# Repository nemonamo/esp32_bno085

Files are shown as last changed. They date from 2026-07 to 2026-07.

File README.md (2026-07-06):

<h1 align="center">ESP32 BNO085</h1>

<p align="center">
  <strong>9축 모션 센싱을 위한 ESP32-S3 + BNO085 KiCad 하드웨어 설계.</strong>
</p>

<p align="center">
  
  
  
  
</p>

<p align="center">
  <a href="#주요-특징">주요 특징</a> |
  <a href="#저장소-구성">구성</a> |
  <a href="#프로젝트-열기">열기</a> |
  <a href="#제작-체크리스트">제작</a> |
  <a href="#라이선스">라이선스</a>
</p>

<p align="center">
  한국어 |
  <a href="docs/i18n/README.en.md">English</a> |
  <a href="docs/i18n/README.zh-CN.md">中文</a> |
  <a href="docs/i18n/README.ja.md">日本語</a>
</p>

이 저장소는 BNO085 9축 스마트 IMU를 중심으로 한 소형 ESP32-S3 보드의 KiCad 설계 파일을 담고 있습니다. 회로도, PCB 레이아웃, 로컬 풋프린트 라이브러리, fabrication-toolkit 설정은 버전 관리하고, 생성된 Gerber와 분석 결과는 Git에 포함하지 않습니다.

## 주요 특징

- **ESP32-S3 모듈** - Wi-Fi/BLE가 가능한 MCU 모듈 풋프린트.
- **BNO085 스마트 IMU** - 가속도계, 자이로, 자력계, 센서 퓨전용 9축 센서.
- **USB-C 인터페이스** - USB 2.0 Type-C 리셉터클 기반 연결.
- **로컬 풋프린트 포함** - BNO085와 Molex 커넥터 풋프린트를 저장소에 포함.
- **제작 설정 버전 관리** - 반복 가능한 제조 파일 생성을 위한 fabrication-toolkit 설정 포함.

## 저장소 구성

```text
esp32_bno085.kicad_pro          KiCad 프로젝트 파일
esp32_bno085.kicad_sch          회로도
esp32_bno085.kicad_pcb          PCB 레이아웃
fp-lib-table                    로컬 풋프린트 라이브러리 테이블
BNO085.pretty/                  BNO085 풋프린트
530480210.pretty/               Molex 커넥터 풋프린트
fabrication-toolkit-options.json
```

생성 파일은 제외합니다.

```text
analysis/
production/
*-backups/
.history/
*.kicad_prl
```

## 프로젝트 열기

1. KiCad 8 이상을 설치합니다.
2. 저장소를 clone합니다.
3. KiCad에서 `esp32_bno085.kicad_pro`를 엽니다.
4. `fp-lib-table` 기준으로 로컬 풋프린트가 정상 연결되는지 확인합니다.
5. 제조 파일을 내보내기 전에 ERC와 DRC를 실행합니다.

```powershell
git clone https://github.com/nemonamo/esp32_bno085.git
cd esp32_bno085
```

## 제작 체크리스트

PCB 주문 전 확인할 항목:

- `esp32_bno085.kicad_sch`에서 KiCad ERC 실행
- `esp32_bno085.kicad_pcb`에서 KiCad DRC 실행
- 현재 보드 기준으로 Gerber, drill, BOM, CPL 재내보내기
- USB D+/D- clearance와 커넥터 방향 확인
- BNO085 I2C pull-up과 전원 레일 확인
- 제작 업체의 설계 규칙이 현재 PCB 제약과 맞는지 확인

이전 보드 리뷰에서는 JLCPCB 관련 copper geometry, 작은 via, USB D- clearance, silkscreen/text warning, BNO085 environmental I2C pull-up을 중점적으로 확인했습니다. 레이아웃을 바꿀 때마다 검사를 다시 실행하세요.

## 이 저장소가 아닌 것

- 펌웨어는 포함하지 않습니다.
- 생성된 production package는 포함하지 않습니다.
- 최신 커밋이 그대로 제작 검증을 마쳤다고 보장하지 않습니다.

## 보안과 안전

하드웨어 저장소도 제작 압축 파일, 공급업체 export, 주문 파일, 스크린샷, 로컬 메모를 통해 개인 정보나 프로젝트 정보를 노출할 수 있습니다. production export와 분석 보고서는 검토 전까지 로컬에만 보관하세요.

## 라이선스

현재 오픈소스 하드웨어/소프트웨어 라이선스가 선언되어 있지 않습니다. 외부 재사용, 제작, 기여를 받기 전에 `LICENSE` 파일을 추가하세요.

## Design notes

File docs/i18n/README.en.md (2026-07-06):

<h1 align="center">ESP32 BNO085</h1>

<p align="center">
  <strong>A compact ESP32-S3 + BNO085 KiCad hardware design for 9-axis motion sensing.</strong>
</p>

<p align="center">
  <a href="../../README.md">한국어</a> |
  English |
  <a href="README.zh-CN.md">中文</a> |
  <a href="README.ja.md">日本語</a>
</p>

This repository contains the KiCad design files for a small ESP32-S3 board built around the BNO085 9-axis smart IMU. Schematic, PCB layout, footprint libraries, and fabrication-toolkit settings are tracked; generated Gerbers and local analysis outputs are excluded.

## Features

- **ESP32-S3 module** - Wi-Fi/BLE capable MCU module footprint.
- **BNO085 smart IMU** - accelerometer, gyroscope, magnetometer, and sensor-fusion capable sensor.
- **USB-C interface** - USB 2.0 Type-C receptacle.
- **Local footprints included** - BNO085 and Molex connector footprint libraries.
- **Fabrication-toolkit settings** - export options for repeatable manufacturing output.

## Repository Contents

```text
esp32_bno085.kicad_pro
esp32_bno085.kicad_sch
esp32_bno085.kicad_pcb
fp-lib-table
BNO085.pretty/
530480210.pretty/
fabrication-toolkit-options.json
```

## Open the Project

```powershell
git clone https://github.com/nemonamo/esp32_bno085.git
cd esp32_bno085
```

Open `esp32_bno085.kicad_pro` in KiCad 8 or newer, confirm local footprints resolve, then run ERC and DRC before exporting fabrication files.

## Fabrication Checklist

- Run KiCad ERC and DRC.
- Re-export Gerbers, drill files, BOM, and CPL.
- Review USB D+/D- clearance and connector orientation.
- Review BNO085 I2C pull-ups and power rails.
- Confirm fabrication-house design rules.

## Security and Safety

Keep generated archives, order files, supplier exports, screenshots, and local notes out of Git unless they have been reviewed.

## License

No open-source hardware or software license is currently declared. Add a `LICENSE` file before publishing this design for reuse, fabrication by others, or external contribution.

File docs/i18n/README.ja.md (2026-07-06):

<h1 align="center">ESP32 BNO085</h1>

<p align="center">
  <strong>9 軸モーションセンシング向け ESP32-S3 + BNO085 KiCad ハードウェア設計。</strong>
</p>

<p align="center">
  <a href="../../README.md">한국어</a> |
  <a href="README.en.md">English</a> |
  <a href="README.zh-CN.md">中文</a> |
  日本語
</p>

このリポジトリは、BNO085 9 軸スマート IMU を中心にした小型 ESP32-S3 ボードの KiCad 設計ファイルを含みます。回路図、PCB、ローカルフットプリント、fabrication-toolkit 設定を管理し、生成済み Gerber や分析出力は含めません。

## 機能

- **ESP32-S3 モジュール** - Wi-Fi/BLE 対応 MCU モジュールのフットプリント。
- **BNO085 スマート IMU** - 加速度、ジャイロ、磁気、センサーフュージョン。
- **USB-C インターフェース** - USB 2.0 Type-C レセプタクル。
- **ローカルフットプリント同梱** - BNO085 と Molex コネクタ用ライブラリ。
- **製造出力設定** - 再現性のある製造ファイル出力用設定。

## 内容

```text
esp32_bno085.kicad_pro
esp32_bno085.kicad_sch
esp32_bno085.kicad_pcb
fp-lib-table
BNO085.pretty/
530480210.pretty/
fabrication-toolkit-options.json
```

## プロジェクトを開く

```powershell
git clone https://github.com/nemonamo/esp32_bno085.git
cd esp32_bno085
```

KiCad 8 以降で `esp32_bno085.kicad_pro` を開き、ローカルフットプリントが解決できることを確認してから、製造ファイル出力前に ERC と DRC を実行してください。

## 製造チェック

- KiCad ERC と DRC を実行する。
- Gerber、ドリル、BOM、CPL を再出力する。
- USB D+/D- のクリアランスとコネクタ向きを確認する。
- BNO085 I2C プルアップと電源レールを確認する。
- 製造業者の設計ルールを確認する。

## 安全性

生成アーカイブ、注文ファイル、サプライヤー出力、スクリーンショット、ローカルメモは、レビュー前に Git に含めないでください。

## ライセンス

現在、オープンソースハードウェアまたはソフトウェアライセンスは宣言されていません。再利用、製造、外部貢献を受ける前に `LICENSE` ファイルを追加してください。

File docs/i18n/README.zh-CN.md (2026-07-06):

<h1 align="center">ESP32 BNO085</h1>

<p align="center">
  <strong>用于 9 轴运动感知的 ESP32-S3 + BNO085 KiCad 硬件设计。</strong>
</p>

<p align="center">
  <a href="../../README.md">한국어</a> |
  <a href="README.en.md">English</a> |
  中文 |
  <a href="README.ja.md">日本語</a>
</p>

本仓库包含围绕 BNO085 9 轴智能 IMU 设计的小型 ESP32-S3 板卡 KiCad 文件。仓库跟踪原理图、PCB、局部封装库和 fabrication-toolkit 设置，不包含生成的 Gerber 和本地分析输出。

## 功能

- **ESP32-S3 模块** - 支持 Wi-Fi/BLE 的 MCU 模块封装。
- **BNO085 智能 IMU** - 加速度计、陀螺仪、磁力计和传感器融合。
- **USB-C 接口** - USB 2.0 Type-C 接口。
- **包含本地封装** - BNO085 和 Molex 连接器封装库。
- **制造导出设置** - 用于可重复生成制造文件。

## 仓库内容

```text
esp32_bno085.kicad_pro
esp32_bno085.kicad_sch
esp32_bno085.kicad_pcb
fp-lib-table
BNO085.pretty/
530480210.pretty/
fabrication-toolkit-options.json
```

## 打开项目

```powershell
git clone https://github.com/nemonamo/esp32_bno085.git
cd esp32_bno085
```

使用 KiCad 8 或更新版本打开 `esp32_bno085.kicad_pro`，确认本地封装可解析，并在导出制造文件前运行 ERC 和 DRC。

## 制造检查

- 运行 KiCad ERC 和 DRC。
- 重新导出 Gerber、钻孔文件、BOM 和 CPL。
- 检查 USB D+/D- 间距和连接器方向。
- 检查 BNO085 I2C 上拉和电源轨。
- 确认制造厂设计规则。

## 安全

生成的压缩包、订单文件、供应商导出、截图和本地笔记在审核前不要提交到 Git。

## 许可证

当前未声明开源硬件或软件许可证。公开复用、制作或接受外部贡献前，请添加 `LICENSE` 文件。

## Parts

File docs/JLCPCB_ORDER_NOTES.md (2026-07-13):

# JLCPCB Order Notes

Last checked: 2026-07-13

Detailed current-state review: [`VERIFICATION_REPORT.md`](VERIFICATION_REPORT.md)

This board keeps the existing outline. Do not enlarge the PCB only to satisfy
assembly handling requirements. If JLCPCB asks for handling area, use a panel,
mouse bites, V-cut, or edge rails around the board.

## Current KiCad Checks

- KiCad 10 ERC: 0 violations.
- KiCad 10 PCB DRC with schematic parity: 0 violations, 0 unconnected items,
  0 schematic parity issues.
- If every project-ignored PCB check is temporarily enabled, the remaining
  warnings are footprint-library comparison warnings (`lib_footprint_mismatch`).
  They indicate that the board-embedded footprint copies differ from the
  currently installed KiCad library versions. They are not clearance,
  unconnected-net, or schematic-parity failures.
- R10/R11 now include B.CrtYd courtyard outlines, so they no longer trigger
  `missing_courtyard` when that normally ignored check is enabled.
- Board outline from the PCB file is about 24.5 mm x 53.4 mm.
- Q1 power-path orientation has been corrected: Q1 gate is on `+5V`, source is
  on `VSYS`, and drain is on `BAT`. This blocks USB-powered `VSYS` from
  backfeeding the battery through the P-MOSFET body diode.

## JLCPCB Assembly Constraints

- The PCB has SMD components on both F.Cu and B.Cu.
- Economic PCBA is single-sided placement. Use Standard PCBA for double-sided
  assembly, or move the assembled parts to one side before using Economic PCBA.
- Standard PCBA currently has a 70 mm x 70 mm minimum single-PCB/panel handling
  size. Keep the board outline unchanged and use a panel/rails if required.
- PCB-only top-side fiducials `FID1`-`FID3` have been added and are excluded
  from BOM and position files. For double-sided Standard PCBA, still review
  JLCPCB's panel/rail/fiducial handling during upload.

## Geometry Notes

- Current project rules use 0.1016 mm minimum track width/clearance.
- JLCPCB's current 1 oz 1/2-layer capability lists 0.10 mm / 0.10 mm minimum
  track width/spacing, so the 0.1016 mm routes are inside that published limit.
- Current default vias are 0.5 mm diameter / 0.3 mm drill. JLCPCB lists
  0.25 mm diameter / 0.15 mm hole as the minimum via capability, with 0.2 mm
  hole preferred, so these vias are not the limiting geometry.
- The USB-C and battery connector footprints intentionally extend to the board
  edge. Some generic DFM analyzers report this as an edge-clearance error, but
  it is not a KiCad DRC violation.
- Gerber analyzer layer-extent warnings are expected here because copper,
  paste, mask, drill, and edge layers naturally occupy different areas of the
  board. KiCad's generated job file reports the complete 24.7 mm x 53.6 mm
  board and all expected Gerber/drill layers are present.

## Via-In-Pad Note

There is a via at/near the D2 pad area. The raw PCB marks that via as capped,
covered, plugged, and filled on both sides. For assembled boards, confirm that
the selected JLCPCB via process honors this, or choose epoxy-filled and capped
or copper-filled and capped vias where needed. JLCPCB notes that vias in pads
cannot be plugged with ink and should use epoxy or copper filling when that
finish is required.

## BOM/CPL Handoff

- Local, ignored-by-git JLCPCB outputs were regenerated under
  `production/jlcpcb_20260713_q1_fix/`: `gerbers.zip`,
  `jlcpcb_bom.csv`, `jlcpcb_cpl_smd_only.csv`, and
  `jlcpcb_cpl_all_components.csv`.
- The normalized BOM has 23 rows. Seven rows have LCSC part numbers and 16 rows
  remain blank until exact lab/JLCPCB part choices are finalized.
- KiCad `MPN`, `Manufacturer`, and `LCSC` fields are populated for seven
  non-generic/order-critical lines: D1, J1, J2, Q1, U1, U3, and U4.
- The exact ESP32-S3 module variant is still intentionally unset. Choose the
  actual flash/PSRAM variant, such as an N8R8 or N16R8 orderable module, before
  filling U2.
- Passives, LEDs, switches, and the 32.768 kHz crystal still need exact
  JLCPCB/LCSC choices for value, tolerance, voltage rating, dielectric, color,
  height, actuator, and load-capacitance details.
- Before ordering assembly, fill exact LCSC part numbers and verify all part
  rotations in the JLCPCB preview, especially USB-C, SOT-23/SOT-23-5, SOIC-8,
  LEDs, and diodes.
- Stock verification is intentionally skipped per user because lab inventory
  covers the parts. If JLCPCB turnkey assembly will source parts from JLC/LCSC
  inventory instead of lab/consigned parts, re-check availability before upload.
- J1 is a through-hole battery header. Confirm Standard PCBA support for that
  line or plan to hand-solder/consign it.
- The current design does not include a USB ESD/EMC filter near J2. This does
  not fail KiCad DRC, but it is still a robustness/EMC tradeoff for production.

## Official References

- PCB capabilities: https://jlcpcb.com/capabilities/pcb-capabilities
- PCBA capabilities: https://jlcpcb.com/capabilities/pcb-assembly-capabilities
- Assembly FAQ: https://jlcpcb.com/help/article/pcb-assembly-faqs
- Via covering: https://jlcpcb.com/help/article/pcb-via-covering

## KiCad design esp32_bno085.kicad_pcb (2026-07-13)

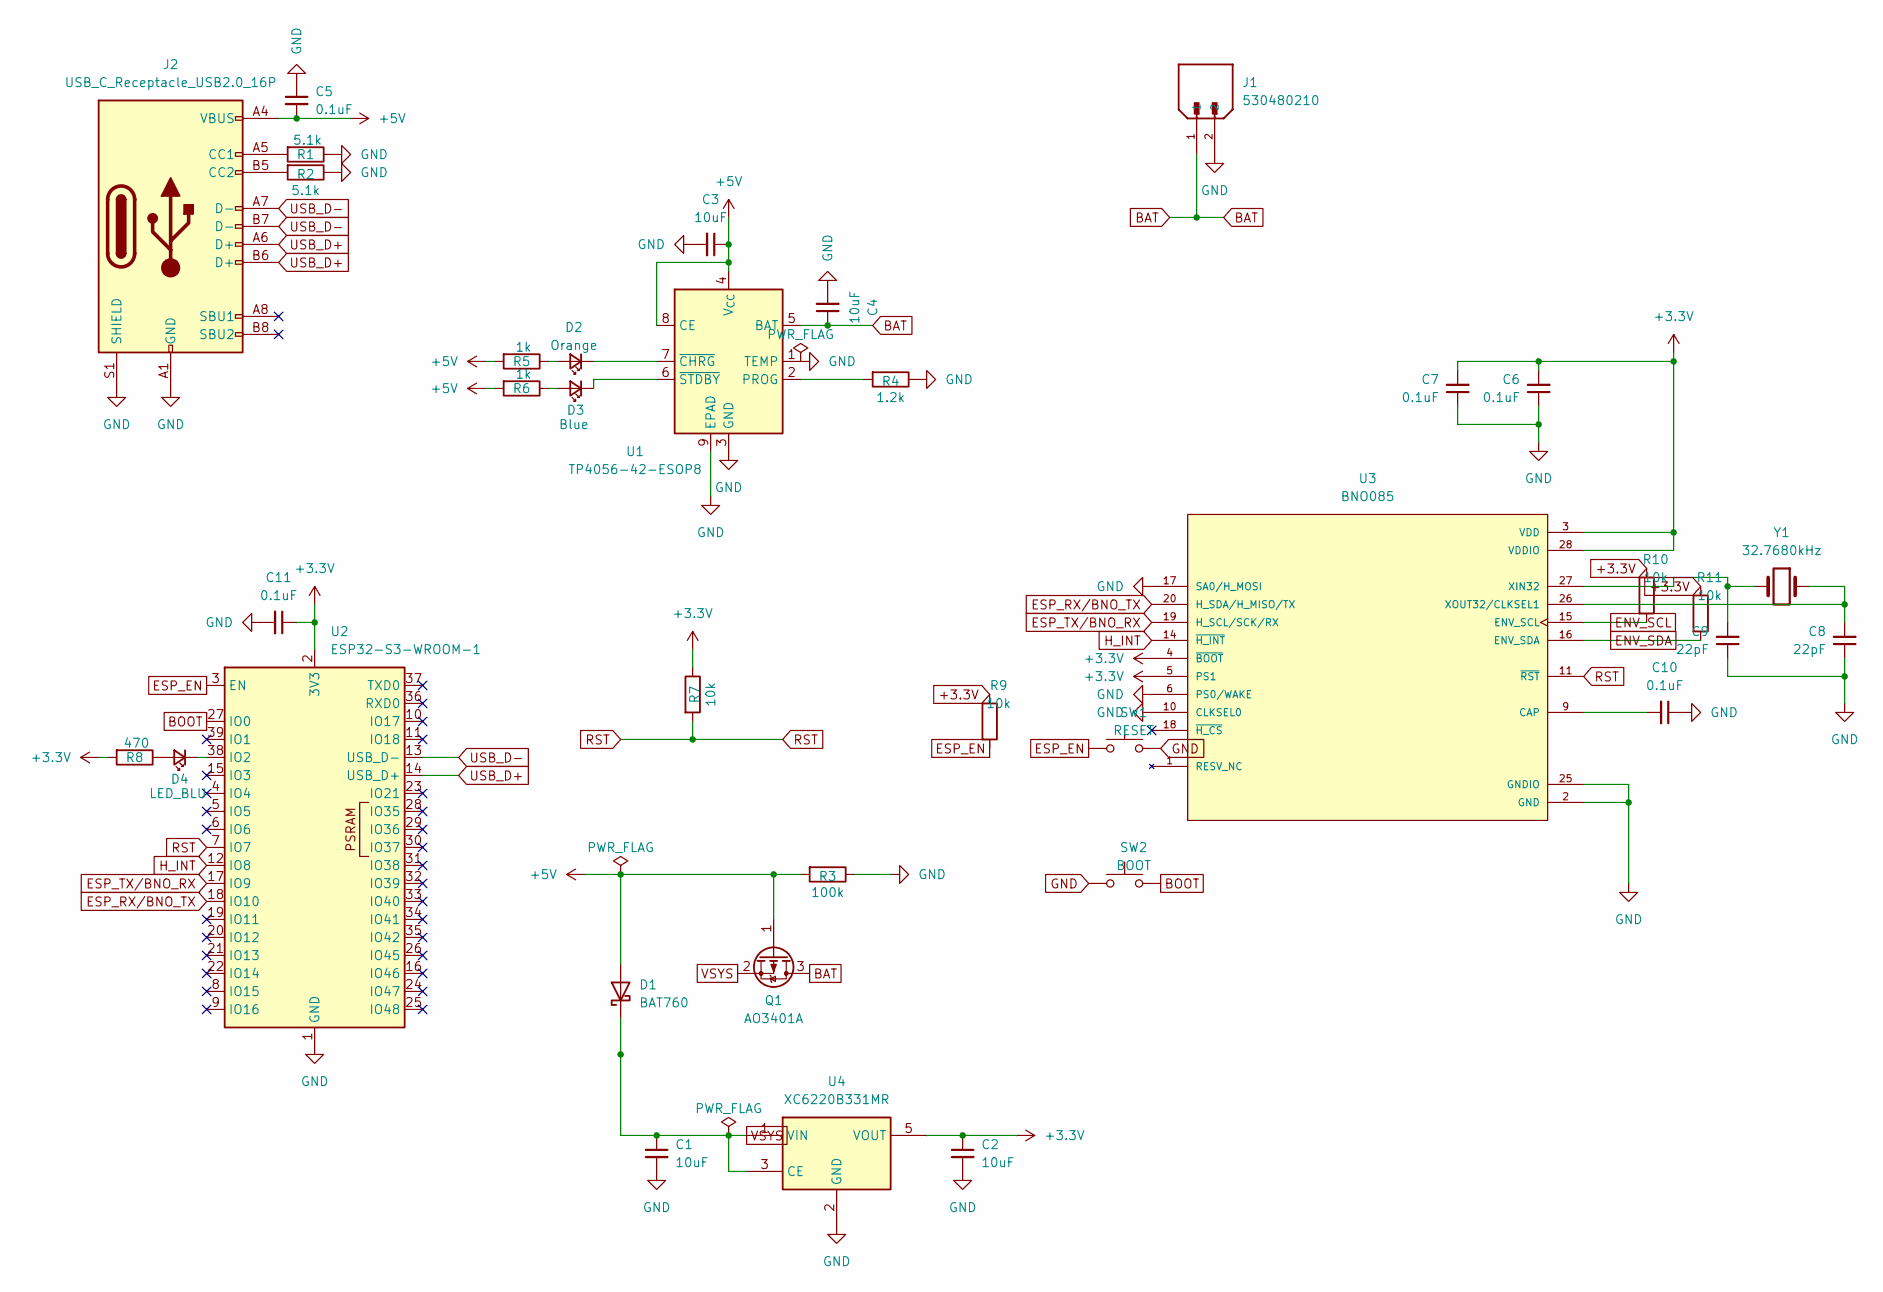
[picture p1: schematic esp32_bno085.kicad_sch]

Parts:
C1, C2, C3, C4: 10uF; C_0402_1005Metric_Pad0.74x0.62mm_HandSolder
C5, C6, C7, C10, C11: 0.1uF; C_0402_1005Metric_Pad0.74x0.62mm_HandSolder
C8, C9: 22pF; C_0402_1005Metric_Pad0.74x0.62mm_HandSolder
D1: BAT760; D_SOD-323; MPN BAT760-7; LCSC C124187
D2: Orange; LED_0603_1608Metric_Pad1.05x0.95mm_HandSolder
D3: Blue; LED_0603_1608Metric_Pad1.05x0.95mm_HandSolder
D4: LED_BLU; LED_0603_1608Metric_Pad1.05x0.95mm_HandSolder
J1: 530480210; MOLEX_530480210; PARTREV A; LCSC C505099
J2: USB_C_Receptacle_USB2.0_16P; USB_C_Receptacle_HRO_TYPE-C-31-M-12; MPN TYPE-C-31-M-12; LCSC C165948
Q1: AO3401A; SOT-23; MPN AO3401A; LCSC C15127
R1, R2: 5.1k; R_0402_1005Metric_Pad0.72x0.64mm_HandSolder
R3: 100k; R_0402_1005Metric_Pad0.72x0.64mm_HandSolder
R4: 1.2k; R_0402_1005Metric_Pad0.72x0.64mm_HandSolder
R5, R6: 1k; R_0402_1005Metric_Pad0.72x0.64mm_HandSolder
R7, R9, R10, R11: 10k; R_0402_1005Metric_Pad0.72x0.64mm_HandSolder
R8: 470; R_0402_1005Metric_Pad0.72x0.64mm_HandSolder
SW1: RESET; SW_SPST_B3U-1000P
SW2: BOOT; SW_SPST_B3U-1000P
U1: TP4056-42-ESOP8; SOIC-8-1EP_3.9x4.9mm_P1.27mm_EP2.41x3.3mm_ThermalVias; MPN TP4056-42-ESOP8; LCSC C16581
U2: ESP32-S3-WROOM-1
U3: BNO085; IC_BNO085; PARTREV v1.17; LCSC C5189642
U4: XC6220B331MR; SOT-23-5; MPN XC6220B331MR-G; LCSC C86534
Y1: 32.7680kHz; Crystal_SMD_3215-2Pin_3.2x1.5mm

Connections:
+3.3V: C2.1, C6.2, C7.2, C11.1, R7.1, R8.2, R9.1, R10.1, R11.1, U2.2 (3V3), U3.3 (VDD), U3.4 (~BOOT), U3.5 (PS1), U3.28 (VDDIO), U4.5 (VOUT)
+5V: C3.1, C5.2, D1.2 (A), J2.A4 (VBUS), J2.A9 (VBUS), J2.B4 (VBUS), J2.B9 (VBUS), Q1.1 (G), R3.2, R5.2, R6.2, U1.4 (V_{CC}), U1.8 (CE)
BAT: C4.1, J1.1, Q1.3 (D), U1.5 (BAT)
BOOT: SW2.2, U2.27 (IO0)
ENV_SCL: R10.2, U3.15 (ENV_SCL)
ENV_SDA: R11.2, U3.16 (ENV_SDA)
ESP_EN: R9.2, SW1.1, U2.3 (EN)
ESP_RX/BNO_TX: U2.18 (IO10), U3.20 (H_SDA/H_MISO/TX)
ESP_TX/BNO_RX: U2.17 (IO9), U3.19 (H_SCL/SCK/RX)
GND: C1.2, C2.2, C3.2, C4.2, C5.1, C6.1, C7.1, C8.1, C9.1, C10.1, C11.2, J1.2, J2.A1 (GND), J2.A12 (GND), J2.B1 (GND), J2.B12 (GND), J2.S1 (SHIELD), R1.1, R2.1, R3.1, R4.1, SW1.2, SW2.1, U1.1 (TEMP), U1.3 (GND), U1.9 (EPAD), U2.1 (GND), U2.40 (GND), U2.41 (GND), U3.2 (GND), U3.6 (PS0/WAKE), U3.10 (CLKSEL0), U3.17 (SA0/H_MOSI), U3.25 (GNDIO), U4.2 (GND)
H_INT: U2.12 (IO8), U3.14 (~H_INT)
unnamed: D2.2 (A), R5.1
unnamed: D2.1 (K), U1.7 (~CHRG)
unnamed: D3.2 (A), R6.1
unnamed: D3.1 (K), U1.6 (~STDBY)
unnamed: D4.2 (A), R8.1
unnamed: D4.1 (K), U2.38 (IO2)
unnamed: J2.A5 (CC1), R1.2
unnamed: J2.B5 (CC2), R2.2
unnamed: R4.2, U1.2 (PROG)
unnamed: C10.2, U3.9 (CAP)
unnamed: C9.2, U3.27 (XIN32), Y1.2
unnamed: C8.2, U3.26 (XOUT32/CLKSEL1), Y1.1
RST: R7.2, U2.7 (IO7), U3.11 (~RST)
USB_D+: J2.A6 (D+), J2.B6 (D+), U2.14 (USB_D+)
USB_D-: J2.A7 (D-), J2.B7 (D-), U2.13 (USB_D-)
VSYS: C1.1, D1.1 (K), Q1.2 (S), U4.1 (VIN), U4.3 (CE)

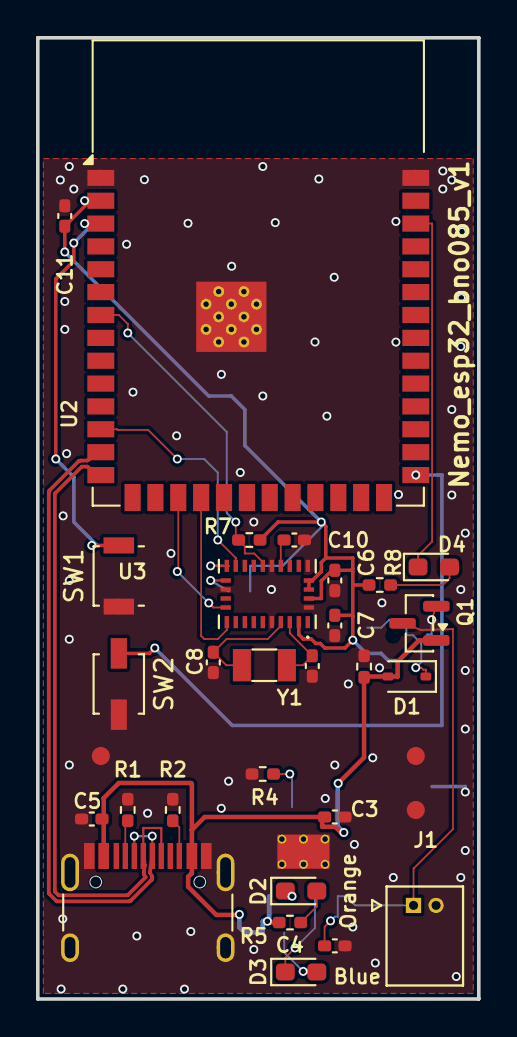
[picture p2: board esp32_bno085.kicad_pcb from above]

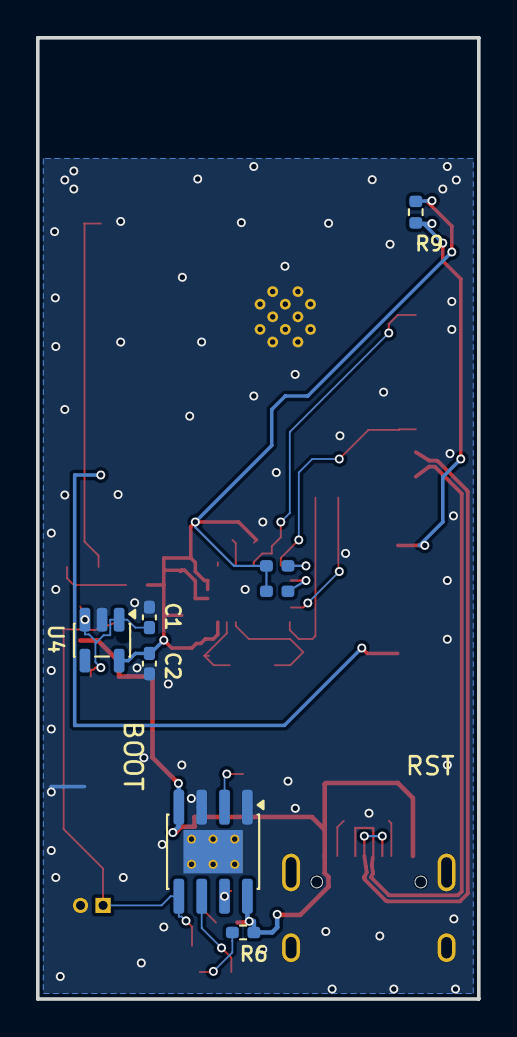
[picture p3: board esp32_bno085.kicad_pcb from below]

Board: 2 copper layers, 24.5 x 53.4 mm, 39 parts (8 on the bottom side), 27 nets.

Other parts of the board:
FID1, FID2, FID3: Fiducial_1mm_Mask2mm

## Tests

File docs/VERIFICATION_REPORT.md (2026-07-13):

# Verification Report

Last checked: 2026-07-13  
Design files checked: current working tree after BOM metadata updates,
PCB-only fiducial additions, and the Q1 power-path orientation fix.

This report is a current-state review, not a blanket guarantee. The board passes
KiCad ERC/DRC, and the main power, USB boot, reset/boot button, and BNO085 mode
connections are internally consistent. It is not fully order-ready for assembled
JLCPCB production until the BOM/LCSC part numbers and placement preview are
completed.

## Checks Run

- KiCad 10 schematic ERC: 0 violations.
- KiCad 10 PCB DRC with zone refill and schematic parity: 0 violations,
  0 unconnected items, 0 schematic parity issues.
- KiCad DRC with all project-ignored checks temporarily enabled:
  32 `lib_footprint_mismatch` warnings only.
- Schematic analyzer: 30 findings.
- PCB analyzer with full coordinate/proximity data: 58 findings.
- Schematic/PCB cross-analysis: 1 finding.
- EMC analyzer: 20 findings, score 31/100.
- Thermal analyzer at 40 C ambient: 0 findings, score 100/100.
- Gerber/drill export and Gerber analyzer: 3 warnings.

The final geometry/signal review outputs are under
`analysis/review_20260713/q1_powerpath_fix/`.

## Critical Bring-Up Checks

### ESP32-S3 USB and Boot

- USB-C VBUS pins A4/A9/B4/B9 connect to `+5V`.
- USB-C D+ pins A6/B6 connect to `USB_D+`.
- USB-C D- pins A7/B7 connect to `USB_D-`.
- ESP32-S3-WROOM-1 pad 14 connects to `USB_D+`.
- ESP32-S3-WROOM-1 pad 13 connects to `USB_D-`.
- CC1 and CC2 each have 5.1k pull-down resistors to GND.
- `SW1 RESET` shorts `ESP_EN` to GND. `ESP_EN` has a 10k pull-up to +3.3V.
- `SW2 BOOT` shorts `BOOT`/GPIO0 to GND.

Conclusion: USB enumeration failure is not explained by missing reset/setup
buttons. The board has both RESET and BOOT buttons, and the USB-C device-side
CC and D+/D- wiring matches the ESP32-S3 native USB pins.

Relevant Espressif references:

- ESP32-S3-WROOM-1 datasheet:
  https://documentation.espressif.com/esp32-s3-wroom-1_wroom-1u_datasheet_en.pdf
- ESP32-S3 hardware design checklist:
  https://docs.espressif.com/projects/esp-hardware-design-guidelines/en/latest/esp32s3/schematic-checklist.html

### Power Tree

- USB `+5V` feeds `VSYS` through D1.
- Battery connector J1 pin 1 feeds `BAT`.
- Battery charger U1 BAT pin is on `BAT`.
- P-channel MOSFET Q1 uses pin 1 gate on `+5V`, pin 2 source on `VSYS`,
  and pin 3 drain on `BAT`.
- R3 pulls the `+5V`/Q1-gate node to GND when USB is absent, enabling battery
  power to `VSYS`.
- U4 XC6220B331MR has VIN and CE on `VSYS`, GND on GND, and VOUT on `+3.3V`.

Conclusion: The schematic/PCB power path is coherent for USB-powered `VSYS`
and battery-powered `VSYS`. The earlier Q1 orientation would have allowed
USB-powered `VSYS` to backfeed `BAT` through the P-MOSFET body diode; that has
been corrected. A board that does not power up should be checked physically at
these points in order: USB VBUS, `VSYS`, U4 VOUT `+3.3V`, ESP32 `EN`.

KiCad ERC also confirms the power source declarations are valid. The existing
PWR_FLAG symbols on the `+5V` and `VSYS` rails are sufficient; adding duplicate
PWR_FLAGs on those same rails creates a power-output-to-power-output ERC error.

Relevant component references:

- XC6220 datasheet:
  https://product.torexsemi.com/system/files/series/xc6220.pdf
- AO3401A datasheet:
  https://www.aosmd.com/res/data_sheets/AO3401A.pdf

### BNO085 Mode and Clock

- BNO085 VDD and VDDIO are on `+3.3V`.
- BNO085 PS1 is tied to `+3.3V`.
- BNO085 PS0/WAKE is tied to GND.
- BNO085 BOOTN is tied high.
- BNO085 XOUT32/CLKSEL1 and XIN32 connect to Y1 with C8/C9 load capacitors.
- BNO085 UART pins connect crosswise:
  `ESP_TX/BNO_RX` to BNO085 pin 19, and `ESP_RX/BNO_TX` to BNO085 pin 20.

Conclusion: The BNO085 is strapped for UART-SHTP mode and has the external
32.768 kHz crystal required for reliable UART operation. BOOTN is tied directly
high; the datasheet recommends a 10k pull-up and optional MCU GPIO for DFU, so
direct high is a robustness/DFU tradeoff rather than a likely power-up blocker.

Relevant CEVA reference:

- BNO08X datasheet:
  https://www.ceva-ip.com/wp-content/uploads/BNO080_085-Datasheet.pdf

## JLCPCB Status

Current board outline is about 24.5 mm x 53.4 mm. Do not enlarge the board
outline for assembly handling. If JLCPCB requires handling area, use a panel,
mouse bites, V-cut, or edge rails around the unchanged board outline.

Current board geometry against JLCPCB published limits:

- Minimum routed signal width is about 0.1016 mm. JLCPCB lists 0.10/0.10 mm
  minimum track width/spacing for 1 oz 1- and 2-layer boards.
- Vias are 0.5 mm diameter / 0.3 mm drill. JLCPCB lists 0.25 mm diameter /
  0.15 mm hole as the 2-layer minimum, with 0.2 mm hole preferred.
- The board has SMD components on both F.Cu and B.Cu. Use Standard PCBA for
  double-sided assembly, or move assembled parts to one side before Economic
  PCBA.
- Three PCB-only top-side fiducials (`FID1`-`FID3`) have been added without
  changing the board outline or BOM. For Standard PCBA handling, still use
  panel/rail support if JLCPCB requires it.

Relevant JLCPCB references:

- PCB capabilities:
  https://jlcpcb.com/capabilities/pcb-capabilities
- PCBA capabilities:
  https://jlcpcb.com/capabilities/pcb-assembly-capabilities
- Assembly FAQ:
  https://jlcpcb.com/help/article/pcb-assembly-faqs
- Via covering:
  https://jlcpcb.com/help/article/pcb-via-covering

## Candidate JLCPCB/LCSC Matches

These are search results for known, non-generic parts. Matching `MPN`,
`Manufacturer`, and `LCSC` fields have been added to the schematic and PCB
footprint properties for the seven rows below. This is not a generated BOM/CPL,
and the matches must still be verified in the JLCPCB upload and placement
preview.

| Ref | Current value | Candidate part | JLCPCB/LCSC # | Notes |
| --- | --- | --- | --- | --- |
| U3 | BNO085 | CEVA BNO085 | C5189642 | JLCPCB lists this as Extended, SMT Assembly, Standard Only, MSL 1, X-ray required. Stock verification is intentionally skipped per user because lab inventory covers the parts; re-check availability only if using JLC-sourced turnkey PCBA. |
| U1 | TP4056-42-ESOP8 | TOPPOWER TP4056-42-ESOP8 | C16581 | JLCPCB lists ESOP-8, SMT Assembly, Economic and Standard, MSL 3. |
| J2 | USB_C_Receptacle_USB2.0_16P | TYPE-C-31-M-12 | C165948 | JLCPCB lists 16P right-angle Type-C, SMT Assembly, Economic and Standard, MSL 1. |
| Q1 | AO3401A | Alpha & Omega Semicon AO3401A | C15127 | JLCPCB lists SOT-23, P-channel, Economic and Standard PCBA. This matches the existing AOS datasheet better than generic AO3401A alternates. |
| U4 | XC6220B331MR | Torex XC6220B331MR-G | C86534 | JLCPCB/LCSC lists the Torex `-G` variant in SOT-25/SOT-23-5 style packaging. The schematic value remains `XC6220B331MR`; the BOM MPN uses the orderable suffix. |
| D1 | BAT760 | DIODES BAT760-7 | C124187 | LCSC lists SOD-323, 30 V, 1 A. Verify package and polarity against the footprint. |
| J1 | 530480210 | Molex 530480210 | C505099 | LCSC lists the 2-pin right-angle PicoBlade header. Confirm JLCPCB PCBA support or plan manual/consigned assembly. |
| U2 | ESP32-S3-WROOM-1 | Not fixed yet | - | Search results include specific flash/PSRAM variants such as `ESP32-S3-WROOM-1-N16R8`; the current schematic value does not specify the exact module variant, so do not auto-fill it. |

Generic resistors, capacitors, LEDs, switches, and the 32.768 kHz crystal still
need exact JLCPCB/LCSC selections for voltage rating, dielectric, tolerance,
height, color/brightness, actuator, and load-capacitance details.

Local, ignored-by-git JLCPCB export files were regenerated under
`production/jlcpcb_20260713_q1_fix/`:

- `gerbers.zip`
- `jlcpcb_bom.csv`
- `jlcpcb_cpl_smd_only.csv`
- `jlcpcb_cpl_all_components.csv`

The normalized BOM expands reference ranges to comma-separated designators and
has 23 rows. Seven rows currently have LCSC part numbers; 16 rows intentionally
remain blank until exact lab/JLCPCB part choices are finalized.

## Remaining Issues Before Ordering

| Item | Severity | Status |
| --- | --- | --- |
| BOM/LCSC/MPN coverage | Blocker for assembled order | Current schematic exports to 23 JLCPCB BOM rows. Seven rows have analyzer-recognized MPN and LCSC fields populated: D1, J1, J2, Q1, U1, U3, U4. The remaining 16 rows, mostly passives/LEDs/switches/crystal and the exact ESP32-S3 module variant, still need final JLCPCB/LCSC selections before turnkey assembled ordering. |
| CPL rotation preview | Blocker for assembled order | Must be checked in JLCPCB preview, especially USB-C, BNO085 LGA, SOT-23, SOT-23-5, SOIC-8, diodes, and LEDs. |
| Standard PCBA handling | Order setup | Board is smaller than Standard PCBA handling size by itself. PCB-only top fiducials were added, but use JLCPCB panel/rails if required; do not alter outline. |
| Via-in-pad / solder wicking | Order setup | Analyzer reports D2 pad 1 as via-in-pad, but the raw PCB via is marked `capping`, `covering`, `plugging`, and `filling` on both sides. If JLCPCB does not honor those per-via attributes, select the filled/capped via option or inspect the assembly preview carefully. |
| USB ESD/filtering | Robustness risk | No USB ESD array or reserved 22/33 ohm series resistor footprints. Espressif recommends reserving USB series resistors and optional capacitors near the chip. This is not a KiCad DRC failure. |
| USB routing symmetry | Robustness risk | Cross-analysis reports USB D+/D- via/layer asymmetry. Full-speed USB is tolerant, but this remains an EMC/SI weakness. |
| EMC score | Robustness risk | EMC analyzer score is 31/100, mostly from no USB filtering, 2-layer adjacent signal layers, USB layer changes, and edge-near sensitive nets. |
| Physical bring-up | Not tested | No measurement evidence yet. Check USB VBUS, `VSYS`, `+3.3V`, `ESP_EN`, and USB D+/D- continuity on a real board. |
| SPICE simulation | Not run | No SPICE simulator was installed in this environment. |
| Lifecycle / stock audit | Skipped by user scope | Stock verification is not required because lab inventory covers the parts. Remaining BOM work is part identity, package fit, assembly method, and CPL rotation/origin review, not availability. |

## Analyzer False Positives or Non-Blockers

- Remaining all-check DRC warnings are `lib_footprint_mismatch`. These mean the
  board-embedded footprint copies differ from the currently installed KiCad
  library versions. They are not clearance, unconnected-net, or schematic-parity
  failures. Do not use "Update Footprints from Library" merely to clear these
  warnings unless the resulting pad/courtyard/connector geometry is reviewed.
- Schematic analyzer `RS-001` warnings on `+5V` and `VSYS` are not KiCad ERC
  failures. Raw ERC testing shows those rails already have PWR_FLAG source
  declarations; duplicating them causes an ERC error.
- `PM-002` on J1/J2 edge distance is expected for edge/overhanging connectors.
- The earlier `FD-001` no-fiducials assembly warning is resolved by PCB-only
  `FID1`-`FID3`. These footprints are excluded from BOM and position files.
- Gerber paste-to-copper ratio warnings are expected because paste layers only
  contain SMD paste apertures, not all copper features.
- Gerber layer-extent alignment warnings are also a heuristic false positive:
  copper, soldermask, paste, drill, silkscreen, and `Edge.Cuts` extents are not
  supposed to have identical occupied bounding boxes on this board. The Gerber
  job file still reports the complete 24.7 mm x 53.6 mm board and all expected
  layers are present.

## Practical Bring-Up Checklist

1. Plug in USB-C and measure J2 VBUS to GND: about 5 V expected.
2. Measure `VSYS`: USB input should appear through D1.
3. Measure U4 VOUT / `+3.3V`: about 3.3 V expected.
4. Measure ESP32 `EN`: normally high, low only while RESET is pressed.
5. Hold BOOT, tap RESET, release RESET, then release BOOT to enter download
   mode.
6. Check USB D+ and D- continuity from J2 to U2 pads 14 and 13.
7. If the PC still does not enumerate, inspect soldering on J2, U2 pins 13/14,
   D1, U4, and the GND shield/pads before changing the schematic.

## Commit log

2026-06-26 Initial KiCad project
    [esp32_bno085.kicad_pcb, esp32_bno085.kicad_sch]
2026-06-26 Clean KiCad DRC warnings
    [esp32_bno085.kicad_pcb, esp32_bno085.kicad_sch]
2026-07-13 Improve JLCPCB assembly via handling
    [esp32_bno085.kicad_pcb]
2026-07-13 Clean up KiCad schematic ERC warnings
    [esp32_bno085.kicad_sch]
2026-07-13 Clarify VSYS rail and JLCPCB order notes
    [esp32_bno085.kicad_pcb, esp32_bno085.kicad_sch]
2026-07-13 Clarify DRC checks and BNO crystal routing
    [esp32_bno085.kicad_pcb, esp32_bno085.kicad_sch]
2026-07-13 Add current verification report
2026-07-13 Clarify power flag verification
2026-07-13 Add JLCPCB BOM metadata fields
    [esp32_bno085.kicad_pcb, esp32_bno085.kicad_sch]
2026-07-13 Clarify stock scope and add PCB fiducials
    [esp32_bno085.kicad_pcb, esp32_bno085.kicad_sch]
2026-07-13 Normalize capacitor BOM value and refresh JLC notes
    [esp32_bno085.kicad_pcb, esp32_bno085.kicad_sch]
2026-07-13 Fix Q1 power path orientation
    [esp32_bno085.kicad_pcb, esp32_bno085.kicad_sch]

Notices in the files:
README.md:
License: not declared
